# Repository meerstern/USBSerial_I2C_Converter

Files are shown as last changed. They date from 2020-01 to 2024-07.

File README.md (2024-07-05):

# USBシリアルI2C変換基板
USB Serial I2C Converter

## 概要 
  * USBシリアルをI2Cマスタに変換する基板です
  * シリアルCOMポートを介してPCやRPI等からI2Cデバイスを制御できます  
  * I2Cデバイスの動作確認やラピッドプロトタイピングに最適です  
  * シリアルCOM変換にPL2303GL、シリアルI2C変換に[SC18IM704][1]を使用しています(V2：現行モデル)  
  * シリアルCOM変換にPL2303SA、シリアルI2C変換にSC18IM700を使用しています(V1：旧モデル)  
  * TeratermやNode-Red、Unity、Python等からシリアルCOMポートを介して容易なコマンドでI2Cデバイスを制御できます  
  * I2CはGrove互換コネクタを搭載しています  
  * Grove互換コネクタの電源、プルアップ抵抗はスイッチ切り替えで5V/3.3Vに対応しています  
    ※USB、I2Cデバイスを接続する前に基板上のシルクを確認してから5V/3.3V切替してください  
    ※3.3V専用デバイスに5Vを加えないように注意してください  

## 詳細 
 * シリアルI2C変換SC18IM700/SC18IM704のコマンドは[データシート(PDF)][8]を参照してください  
 * シリアルI2C変換[SC18IM700/SC18IM704][1]のデフォルトボーレートは9600bpsです  
 * アドレスの異なる複数のデバイスを接続する場合は[I2Cハブ][7]を使用してください
 * 基板のピンヘッダを用いることでSC18IM700/SC18IM704単体の変換基板としても使用できます  
 * USB5V電源入力側に350mA定格のリセッタブルヒューズを搭載しています  
 * 給電可能な電流は3.3Vラインで最大150mA前後、5Vラインで最大350mAです
 * コマンドの応答がない場合はピンセット等でRSTピンとGNDピンを1秒程度短絡してリセットさせてください    

## USBドライバ
 * Windows版は[こちらからダウンロード][2]して使用してください  
 ※標準ドライバではNode-Redで動作不具合があるため、最新のドライバに更新し、再起動後に使用してください
 * Mac版は標準でドライバが読み込まれますが、必要に応じて[こちらからダウンロード][3]して使用してください  
 * Linux版はKernel 2.4.31以降、標準でドライバが組み込まれています  

## Node-Redサンプルフロー
 * シリアルポートフローを使用して[Grove温湿度センサSHT31][5]から温度、湿度を読み込む[サンプル][4]  
 * 温湿度センサ　SHT31、I2C接続LCD AQM1602、マルチ環境センサBME280、CO2センサ CCS811、リアルタイムクロック DS1307、AD変換 MCP3425、粒子センサ HM3301、赤外線グリッドセンサAMG8833、I2Cデバイス検索のサンプルコードがあります  
 ※詳細はサンプルコードをご確認ください  
 ※シリアルポートフローを使用する場合はオンプレミス版Node-Redを使用する必要があります。[こちらの記事][6]を参考にしてください  
 
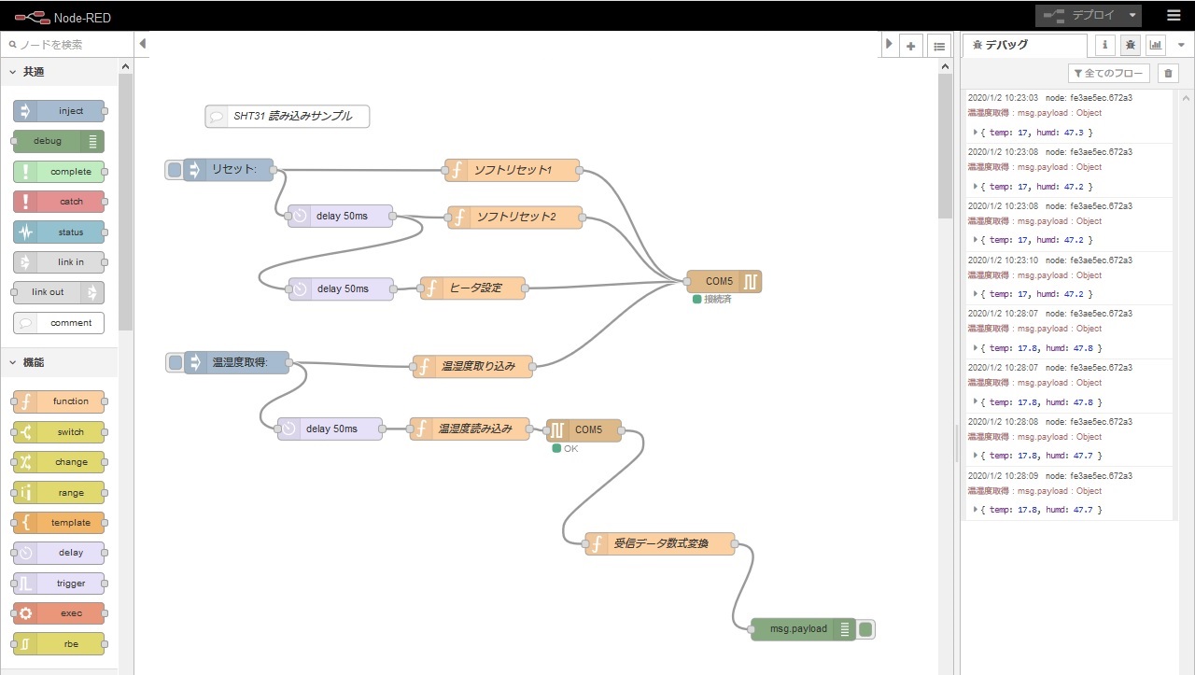
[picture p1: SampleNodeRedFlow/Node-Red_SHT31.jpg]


## Teratermサンプルマクロ
 * サンプルマクロを実行する際には必ず言語設定を「English」、「Default.lng」に設定してください。正しく送受信されません。  

## WebシリアルAPIツール
 * WebシリアルAPIを使用した[ツールを公開][9]しています  
 * EdgeもしくはChromeブラウザからアクセスすると簡単にI2Cデバイスと通信できます  
 * 対応デバイスは随時追加予定です  

## 変換基板
 * USBシリアルI2C変換基板の外観  

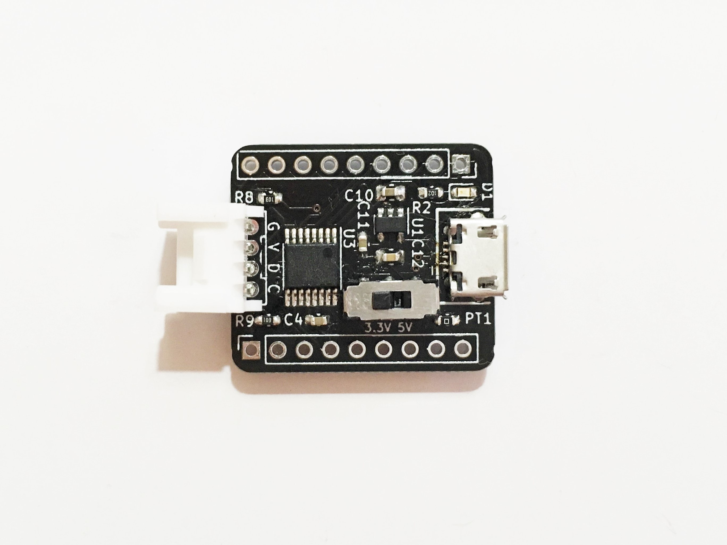
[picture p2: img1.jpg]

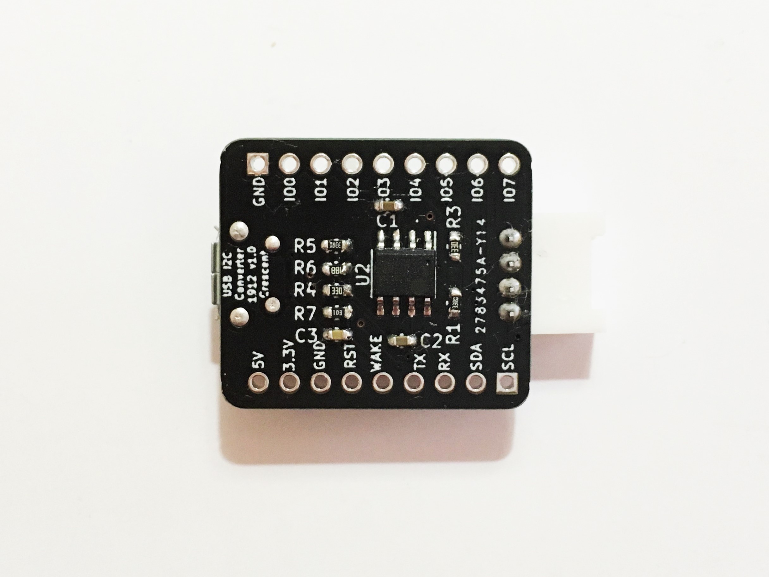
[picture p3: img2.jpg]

 
 ※上記写真は試作基板のため、量産版と異なる場合があります  
 
 ## 販売サイト
  * [スイッチサイエンス][10]
  
 ## 告知
  * SC18IM700、PL2303SAは生産完了のため、23年7月以降はそれぞれ後継機種のSC18IM704、PL2303GLを使用したv2.x基板に変更しました
  * SC18IM700/SC18IM704の基本的なI2Cコマンド等は互換性が維持されています
  * 生産完了に伴い、v1.xモデルの製造及び販売は終了しました  

# USB Serial I2C Converter
## Overview 

  * This is a board that converts USB serial to I2C master.
  * Can control I2C devices from PC, RPI, etc. via serial COM port
  * Ideal for I2C device operation verification and rapid prototyping
  * PL2303GL is used for serial COM conversion, and [SC18IM704][1] is used for serial I2C conversion (V2: current model)
  * Control I2C devices with easy commands via serial COM port from Teraterm, Node-Red, Unity, Python, etc.
  * I2C has Grove compatible connector  
  * Grove compatible connector power supply and pull-up resistor support 5V/3.3V by switching
  * Before connecting USB or I2C devices, please check the silk on the board and then switch 5V/3.3V.
  * Please be careful not to apply 5V to 3.3V only devices.

## Details 
  * For serial I2C conversion SC18IM700/SC18IM704 commands, please refer to [Datasheet (PDF)][8]
  * The default baud rate for serial I2C conversion [SC18IM700/SC18IM704][1] is 9600bps
  * When connecting multiple devices with different addresses, please use [I2C hub][7]
  * Can also be used as a conversion board for SC18IM700/SC18IM704 by using the pin header on the board
  * Equipped with a resettable fuse rated at 350mA on the USB5V power input side
  * The maximum current that can be supplied is around 150mA for 3.3V line, and 350mA for 5V line.
  * If there is no response to the command, short the RST pin and GND pin with tweezers for about 1 second to reset.

  ## USB Driver
  * For Windows version, please [download][2] from here.
  * The standard driver has a malfunction with Node-Red, so please update to the latest driver and use it after restarting.
  * The driver is loaded by default in the Mac version, but if necessary, please [download][3].
  * The Linux version has a built-in driver as standard since Kernel 2.4.31 

 ## Node-Red Sample Flow
  * Read temperature and humidity from [Grove temperature and humidity sensor SHT31][5] using serial port flow [sample][4]
  * Temperature and humidity sensor SHT31, I2C connection LCD AQM1602, multi-environment sensor BME280, CO2 sensor CCS811, real-time clock DS1307, AD conversion MCP3425, particle sensor HM3301, infrared grid sensor AMG8833, sample code for I2C device search is available
  * Please check the sample code for details.
  * If you want to use serial port flow, you need to use the on-premises version of Node-Red. Please refer to [this article(Japanese)][6]
 


## Teraterm Sample Macro
 * When running the sample macro, be sure to set the language settings to "English" and "Default.lng". It will not be sent or received correctly.

## Web Serial API Tools
 * [Publishing tools][11] using Web Serial API
 * Easily communicate with I2C devices when accessed from Edge or Chrome browsers
 * Compatible devices will be added

 ## Announcement
  * Production of SC18IM700 and PL2303SA has been discontinued, so from July 2023 onwards, we have changed to v2.x boards using the successor models SC18IM704 and PL2303GL, respectively.
  * Compatibility of basic I2C commands etc. of SC18IM700/SC18IM704 is maintained.
  * Due to the completion of production, the manufacture and sale of v1.x model has ended.

[1]: https://www.nxp.jp/part/SC18IM704PW#/
[2]: https://www.prolific.com.tw/UserFiles/files/PL23XX_Prolific_DriverInstaller_v408.zip
[3]: https://www.prolific.com.tw/UserFiles/files/PL2303HXD_G_Mac%20Driver_v2_1_0_20210311.zip
[4]: https://github.com/meerstern/USBSerial_I2C_Converter/tree/master/SampleNodeRedFlow
[5]: https://www.switch-science.com/catalog/2853/
[6]: http://meerstern.seesaa.net/article/465007276.html
[7]: https://www.switch-science.com/catalog/796/
[8]: https://www.nxp.jp/docs/en/data-sheet/SC18IM704.pdf
[9]: https://meerstern.github.io/
[10]: https://www.switch-science.com/products/6214
[11]: https://meerstern.github.io/Web%20API%20Tools_En.html

MIT Lisense

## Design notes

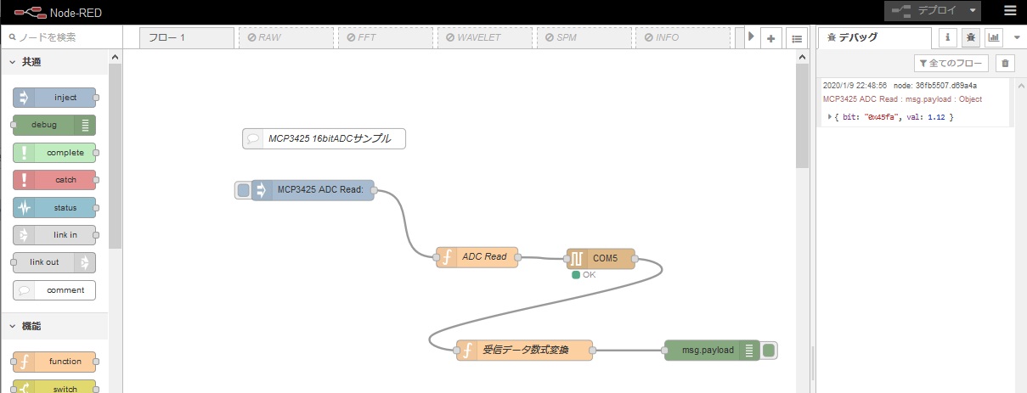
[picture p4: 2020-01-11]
SampleNodeRedFlow/Node-Red_MCP3425.jpg

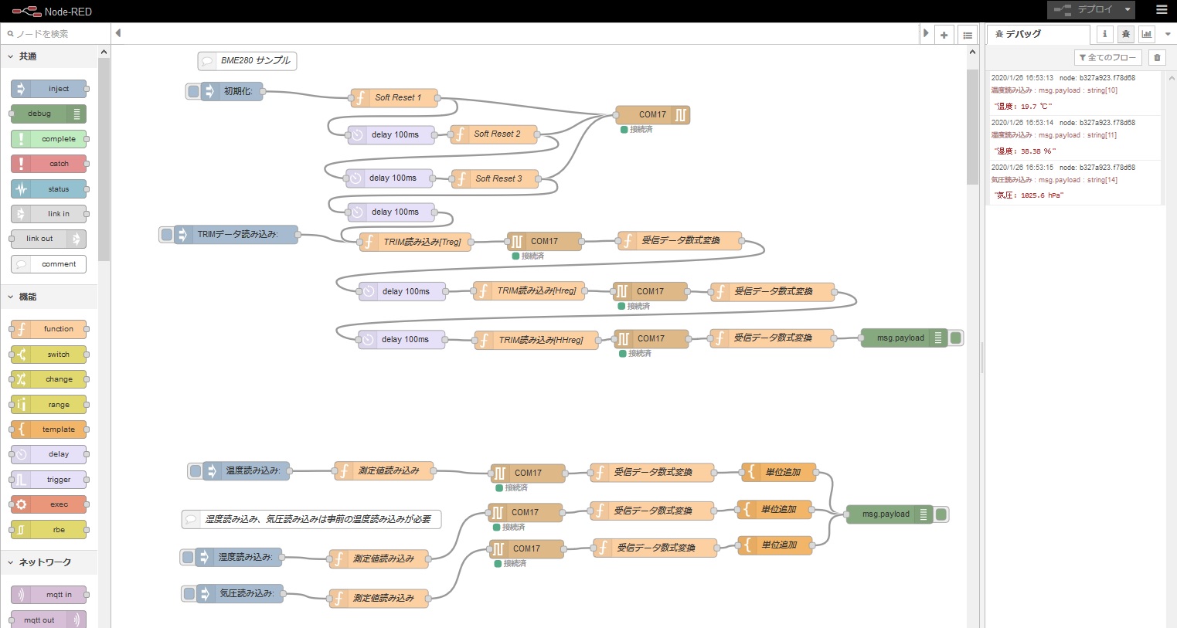
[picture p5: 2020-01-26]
SampleNodeRedFlow/Node-Red_BME280.jpg

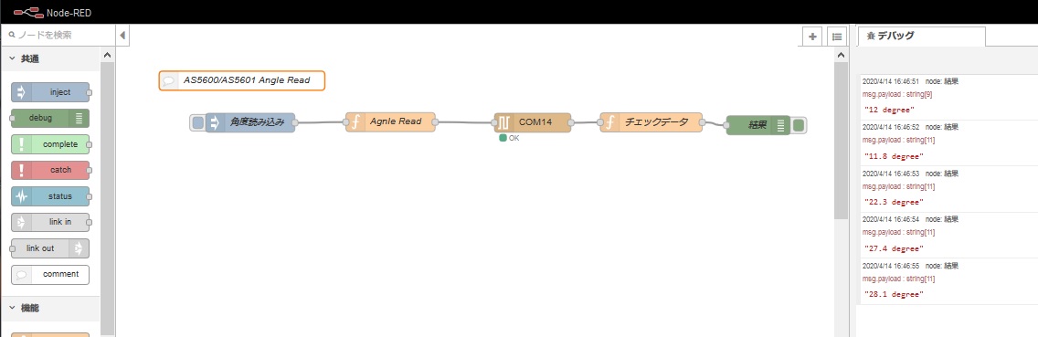
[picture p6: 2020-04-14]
SampleNodeRedFlow/Node-Red_AS5600,AS5601.jpg

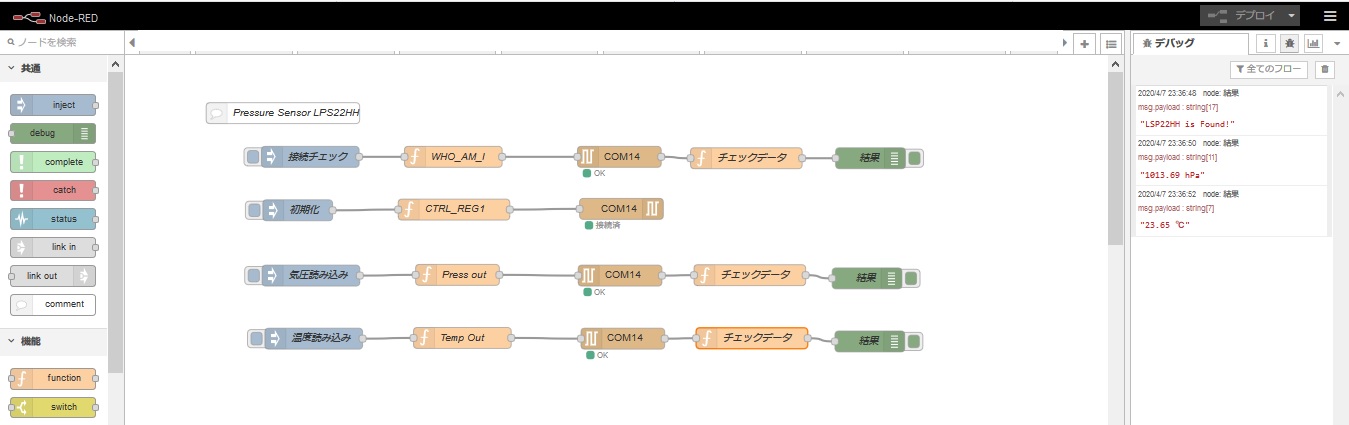
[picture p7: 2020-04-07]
SampleNodeRedFlow/Node-Red_LPS22HH.jpg

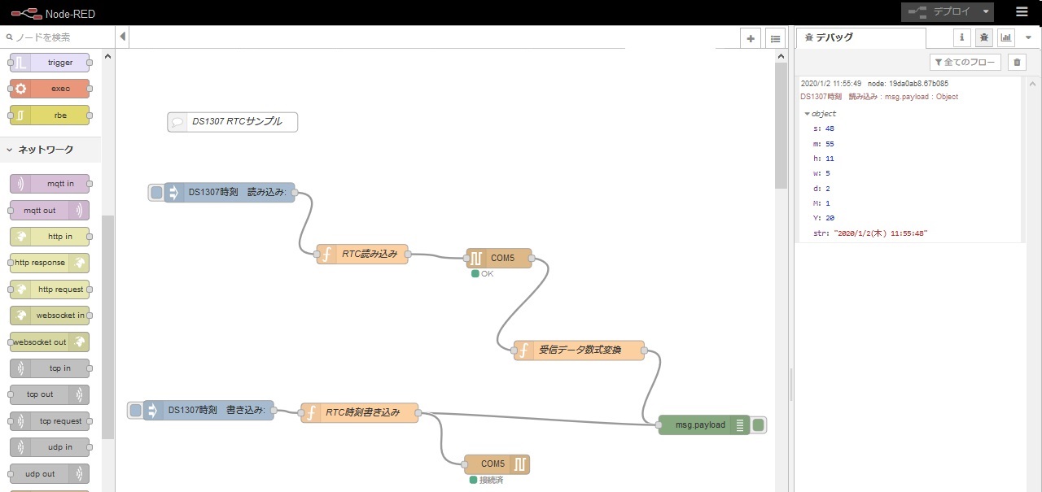
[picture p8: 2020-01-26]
SampleNodeRedFlow/Node-Red_DS1307.jpg

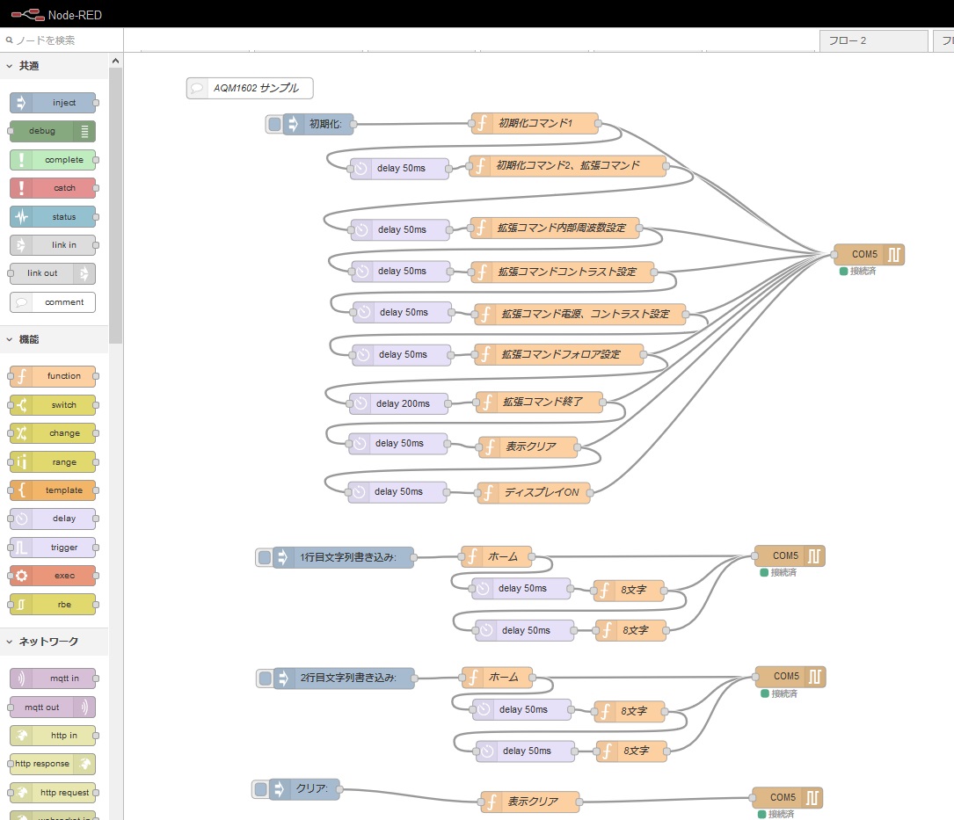
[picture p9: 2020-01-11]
SampleNodeRedFlow/Node-Red_AQM1602.jpg

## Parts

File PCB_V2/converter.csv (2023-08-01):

ID | 参照記号 | パッケージ | 数 | 名称 | Supplier and ref
1 | R10,R7 | R_0603_1608Metric | 2 | 10k
2 | U3 | TSSOP-16_4.4x5mm_P0.65mm | 1 | SC18IM704
3 | C1,C2,C4 | C_0603_1608Metric | 3 | 0.1u
4 | C10,C12 | C_0805_2012Metric | 2 | 10u
5 | C11 | C_0603_1608Metric | 1 | 0.01u
6 | D1 | LED_0603_1608Metric | 1 | LED
7 | M1 | CONN-10118194-0001LF-FCI | 1 | MICRO-USB-ZX62R-B-5P-con-hirose
8 | PT1 | R_0603_1608Metric | 1 | femtoSMDC035F-02
9 | R1,R3,R4,R5 | R_0603_1608Metric | 4 | 27
10 | R2 | R_0603_1608Metric | 1 | 1k
11 | R6 | R_0603_1608Metric | 1 | 1.5k
12 | U1 | SOT-23-5 | 1 | LD3985M33R
13 | U2 | SOIC-8_3.9x4.9mm_P1.27mm | 1 | PL2303SA
14 | J1 | GROVE | 1 | Conn_01x04
15 | J2,J3 | PinSocket_1x09_P2.54mm_Vertical | 2 | Conn_01x09
16 | R8,R9 | R_0603_1608Metric | 2 | 4.7k
17 | SW1 | DPDT_SMD | 1 | SW_SPDT

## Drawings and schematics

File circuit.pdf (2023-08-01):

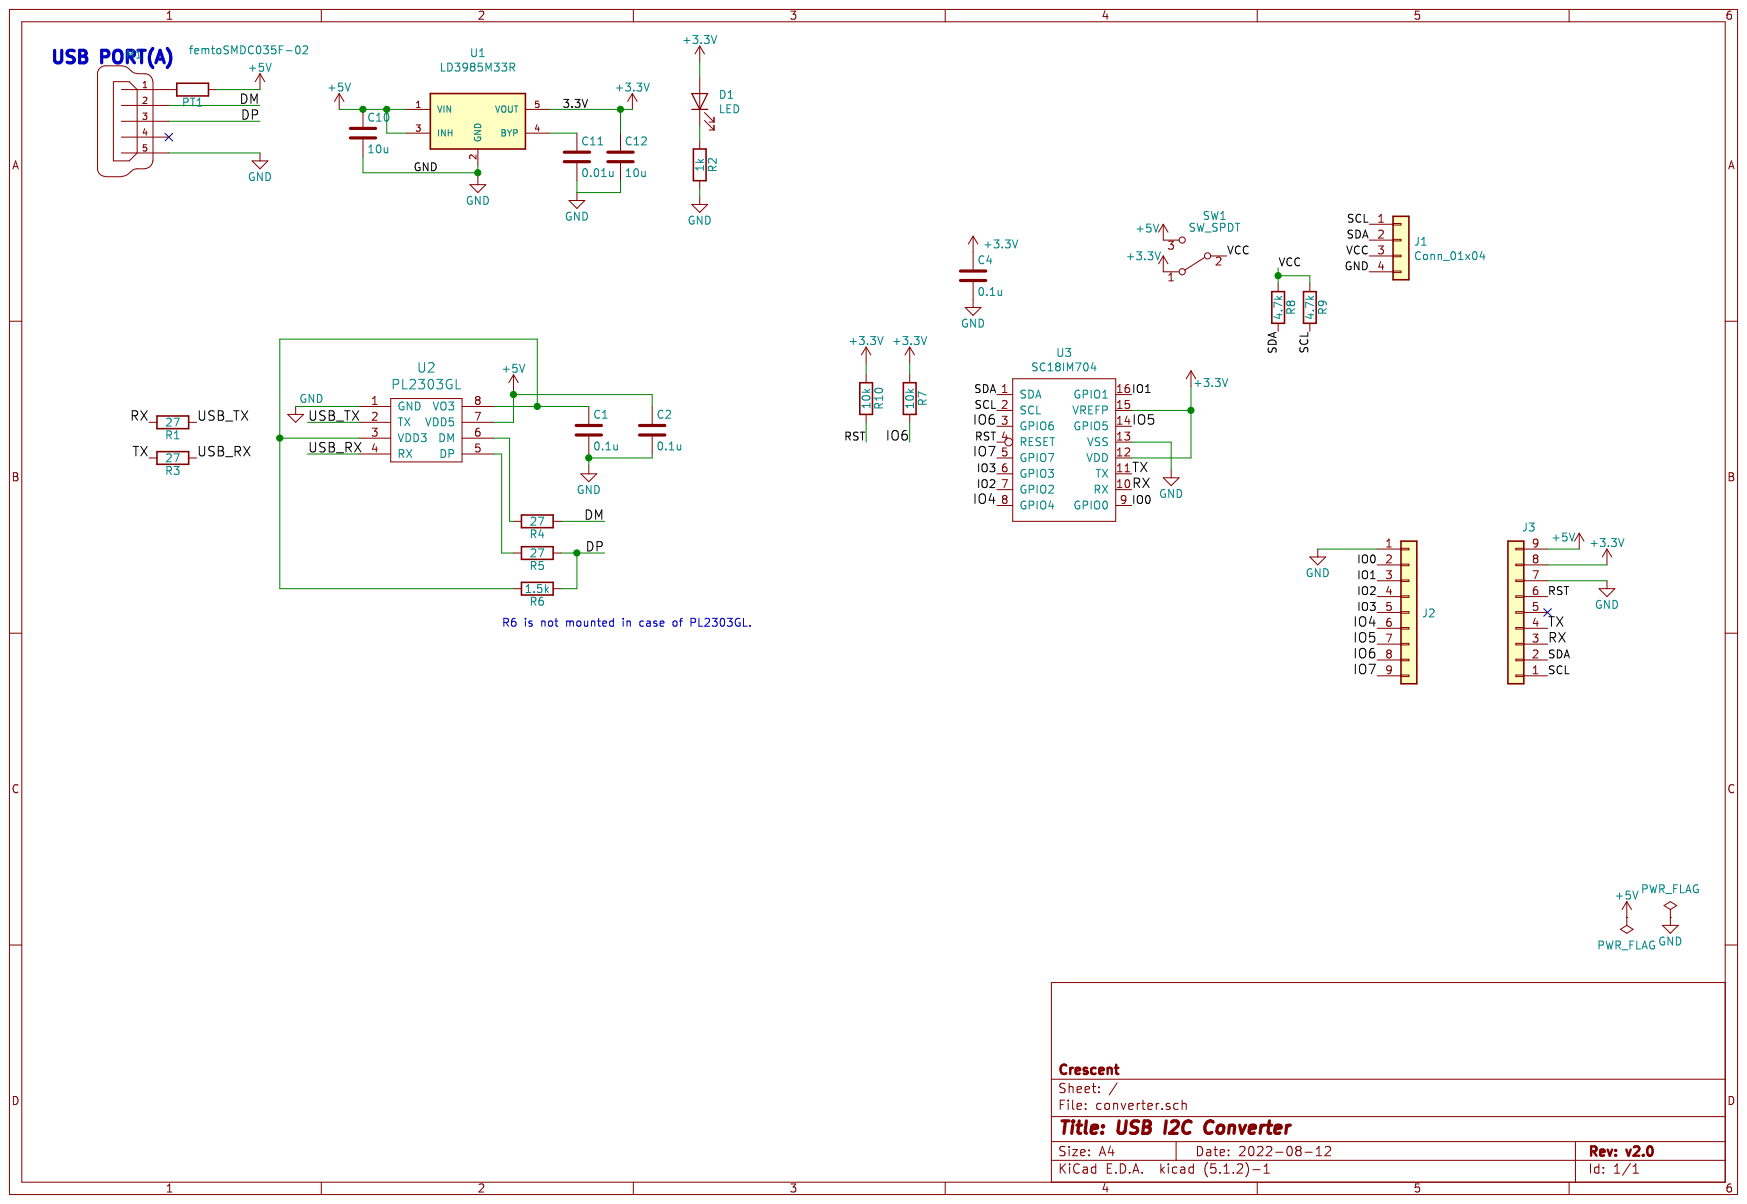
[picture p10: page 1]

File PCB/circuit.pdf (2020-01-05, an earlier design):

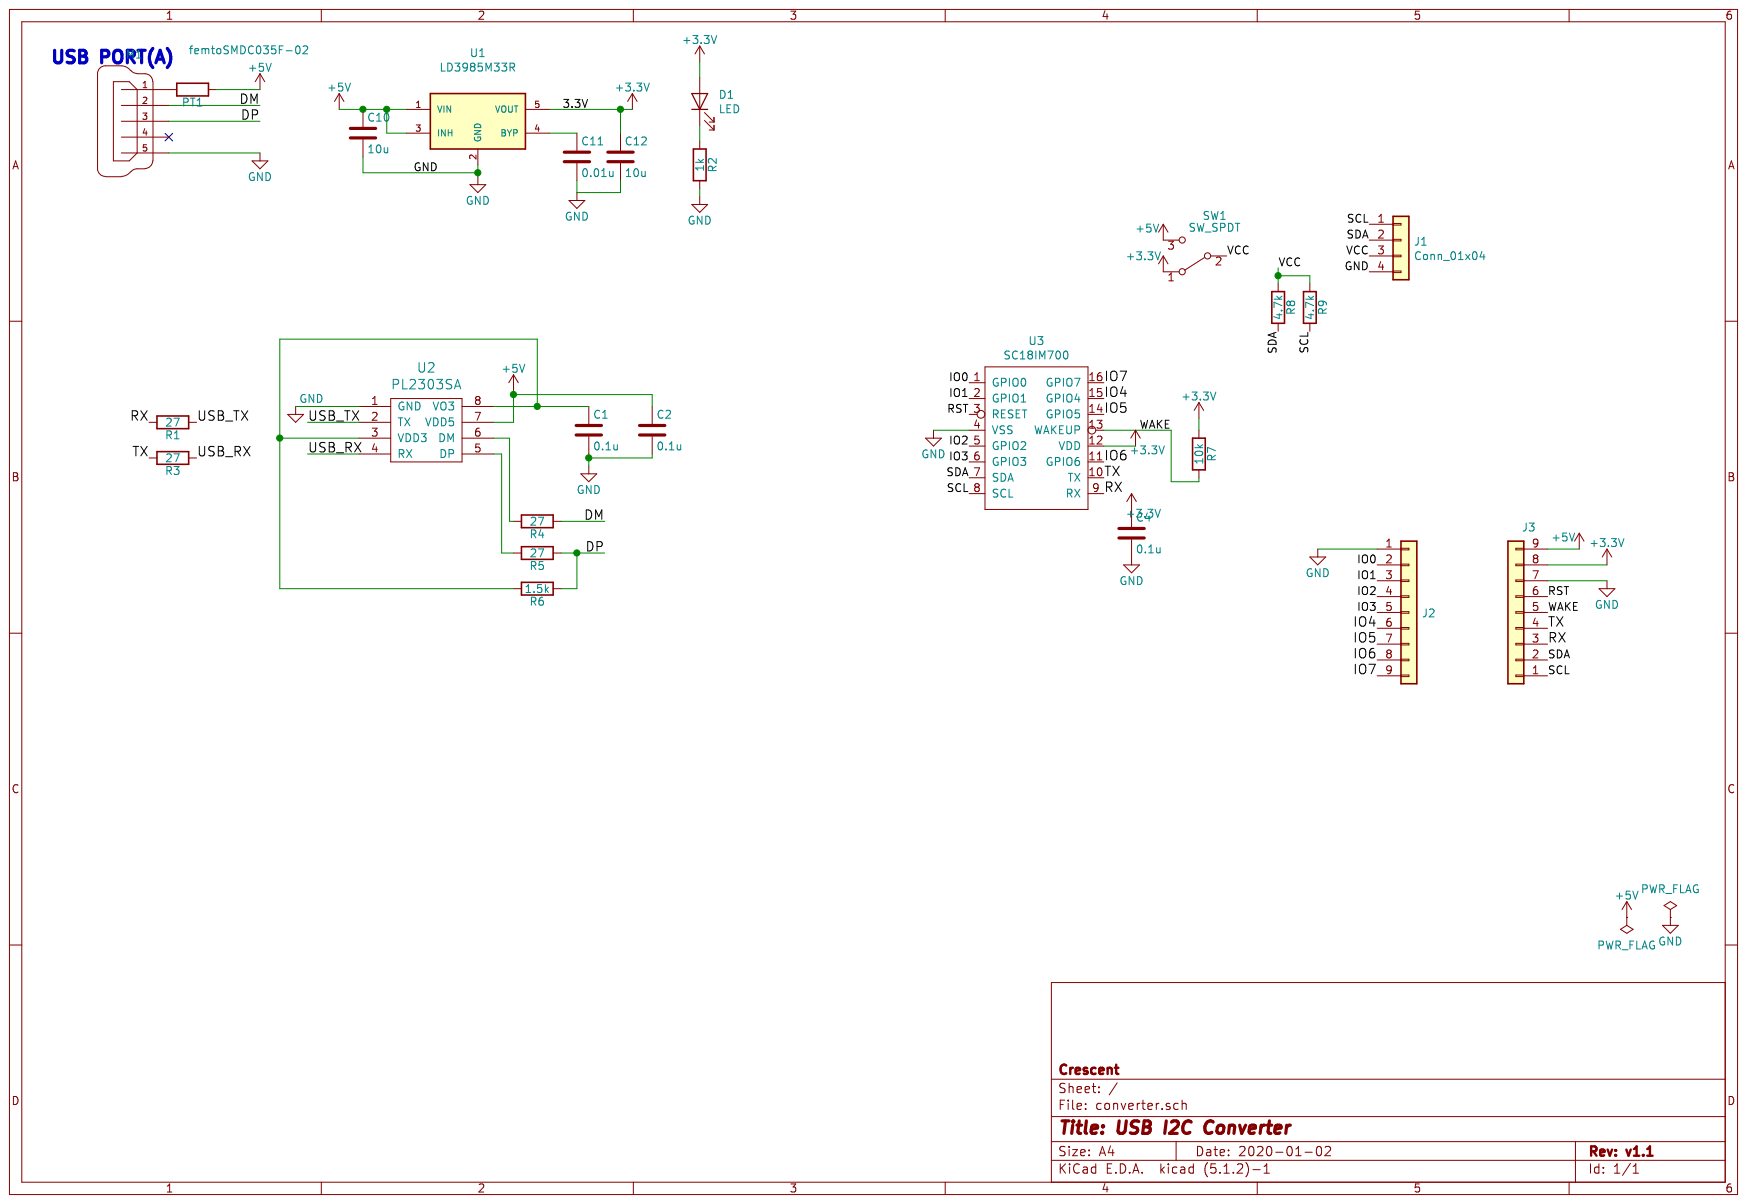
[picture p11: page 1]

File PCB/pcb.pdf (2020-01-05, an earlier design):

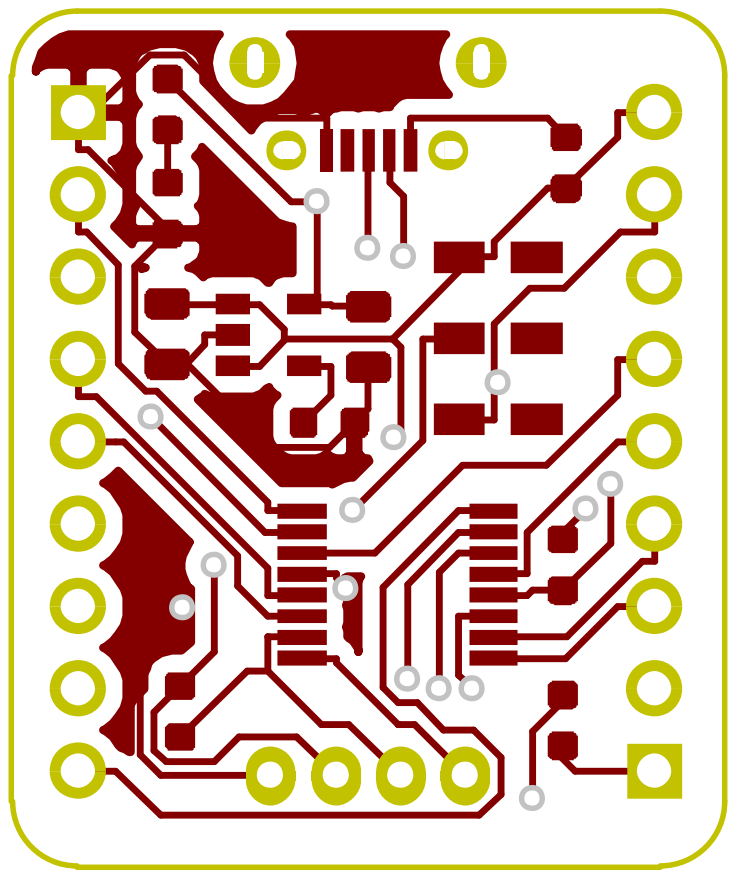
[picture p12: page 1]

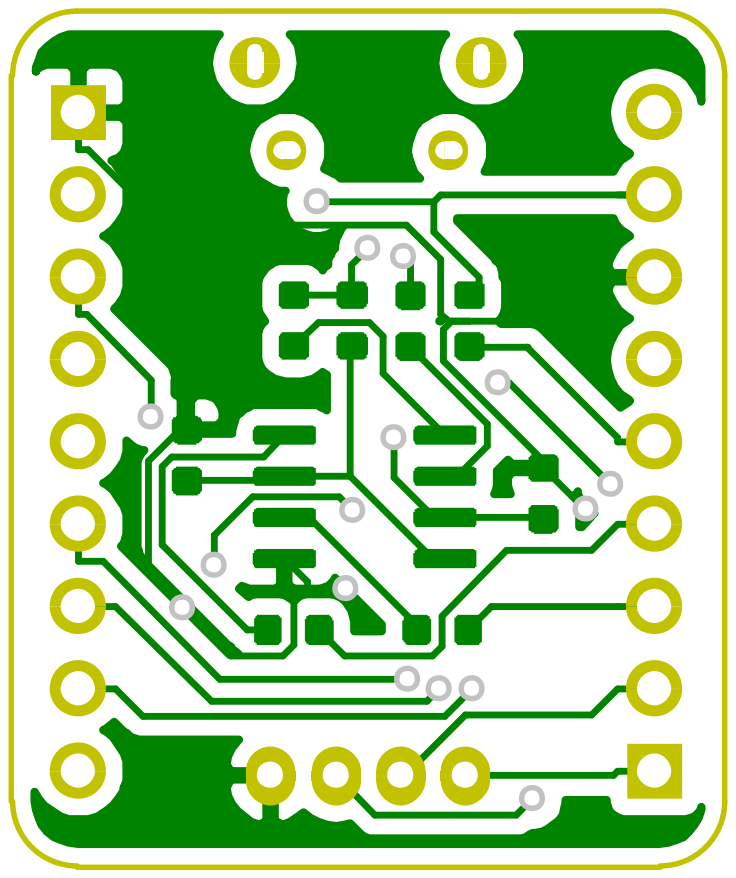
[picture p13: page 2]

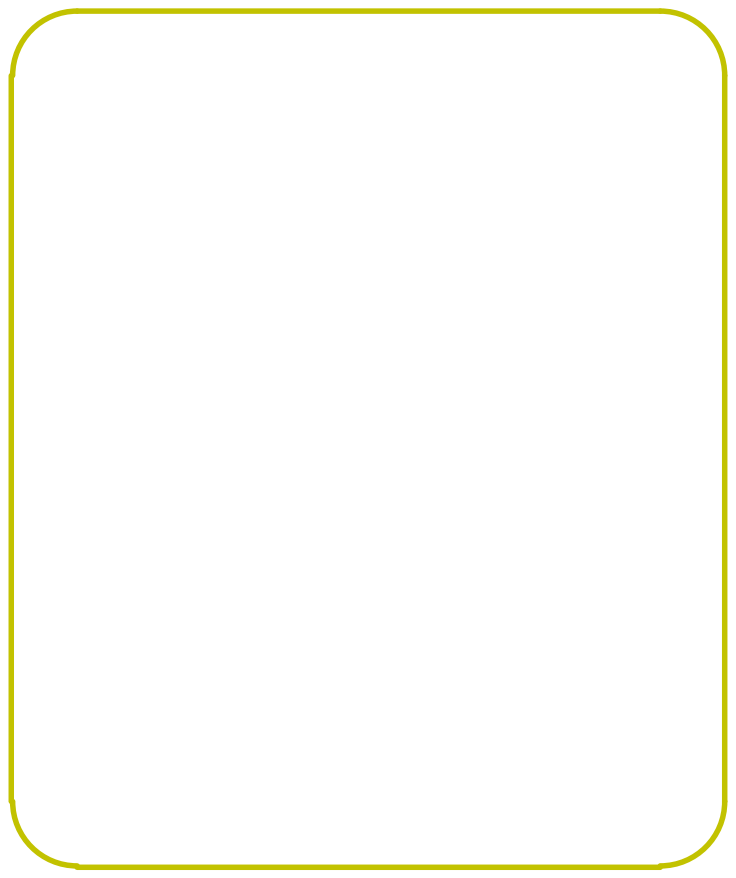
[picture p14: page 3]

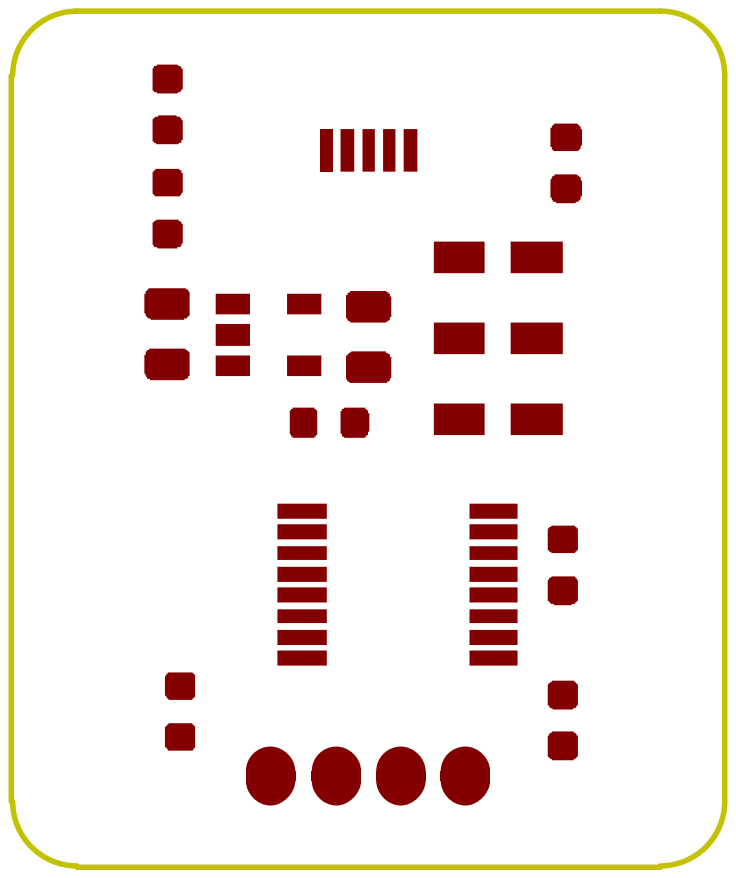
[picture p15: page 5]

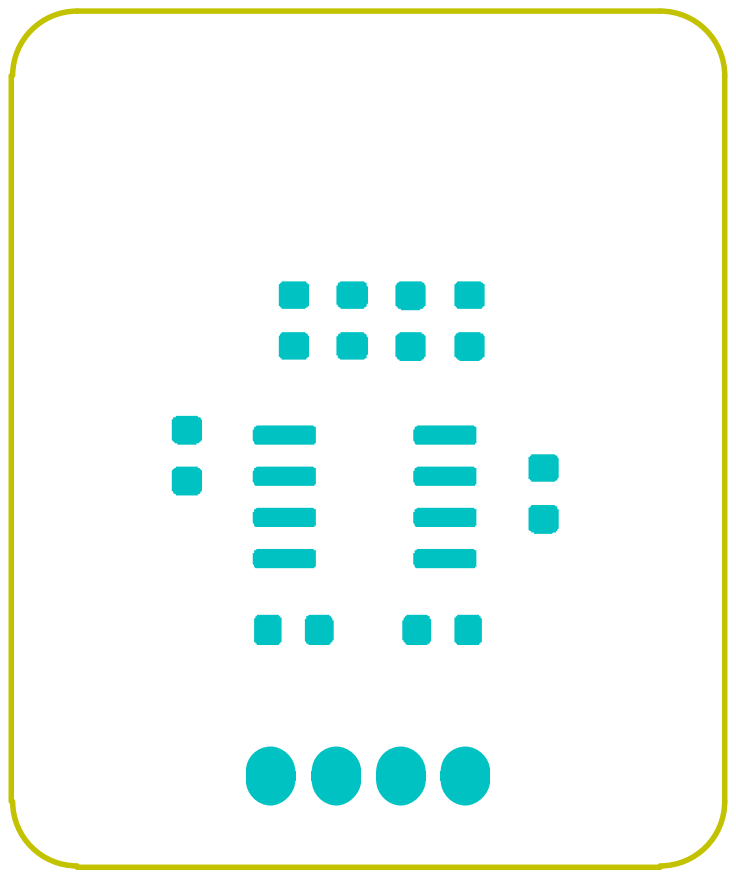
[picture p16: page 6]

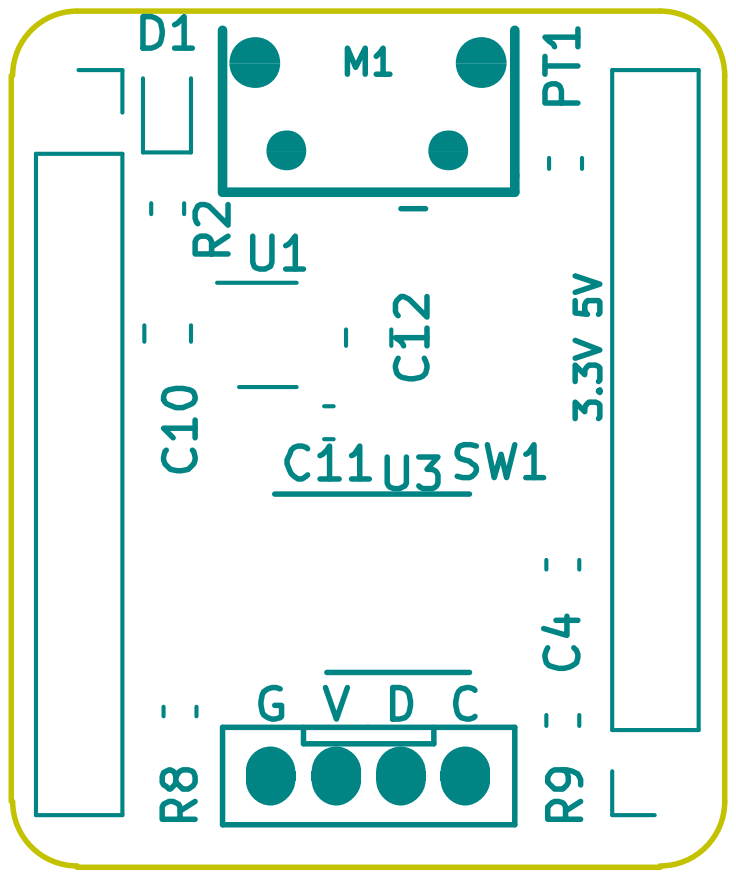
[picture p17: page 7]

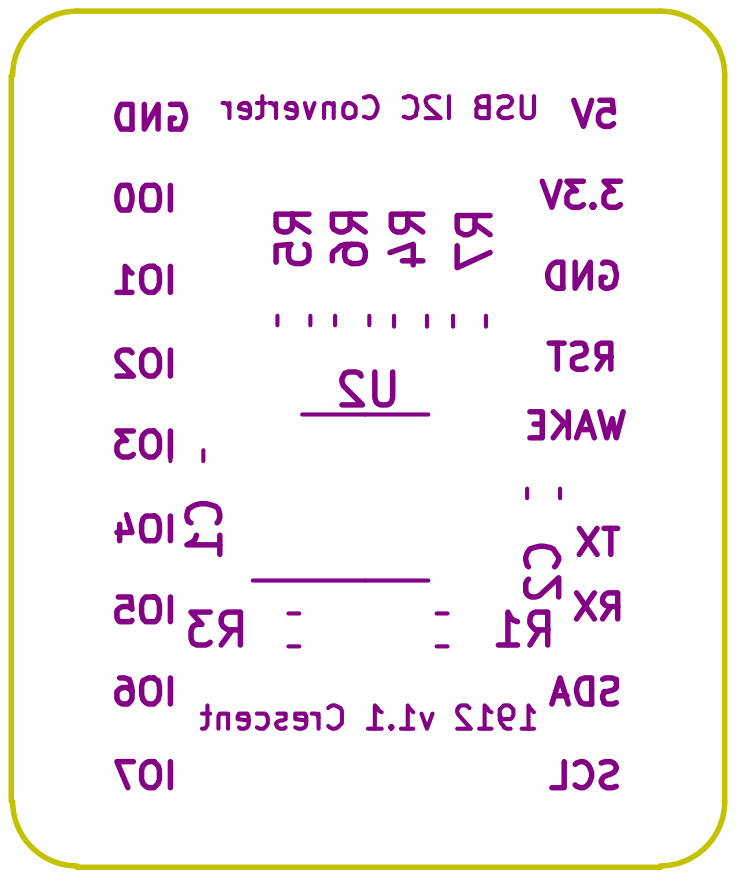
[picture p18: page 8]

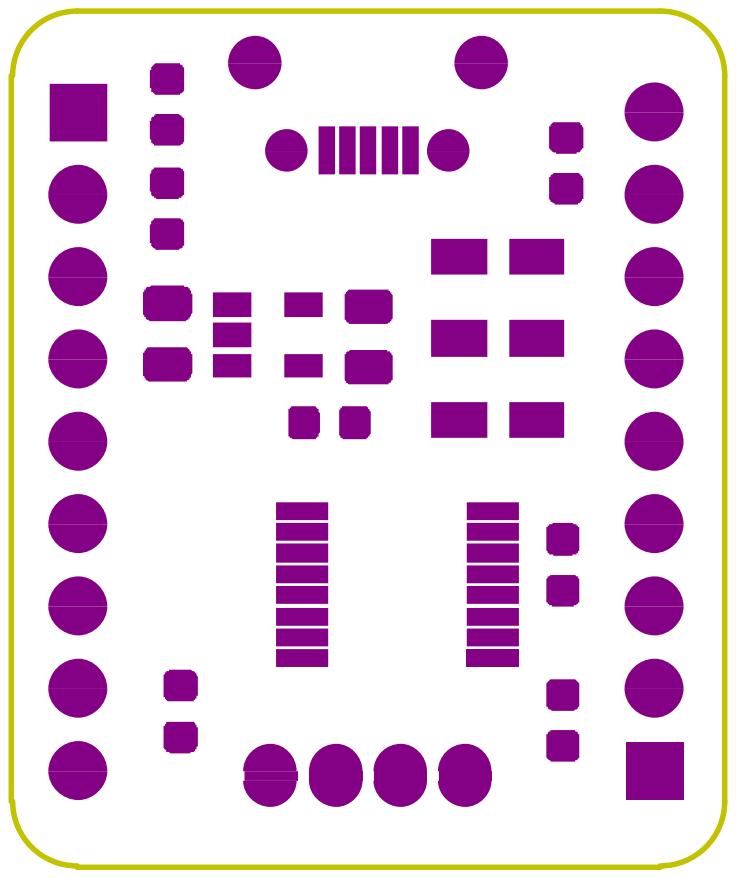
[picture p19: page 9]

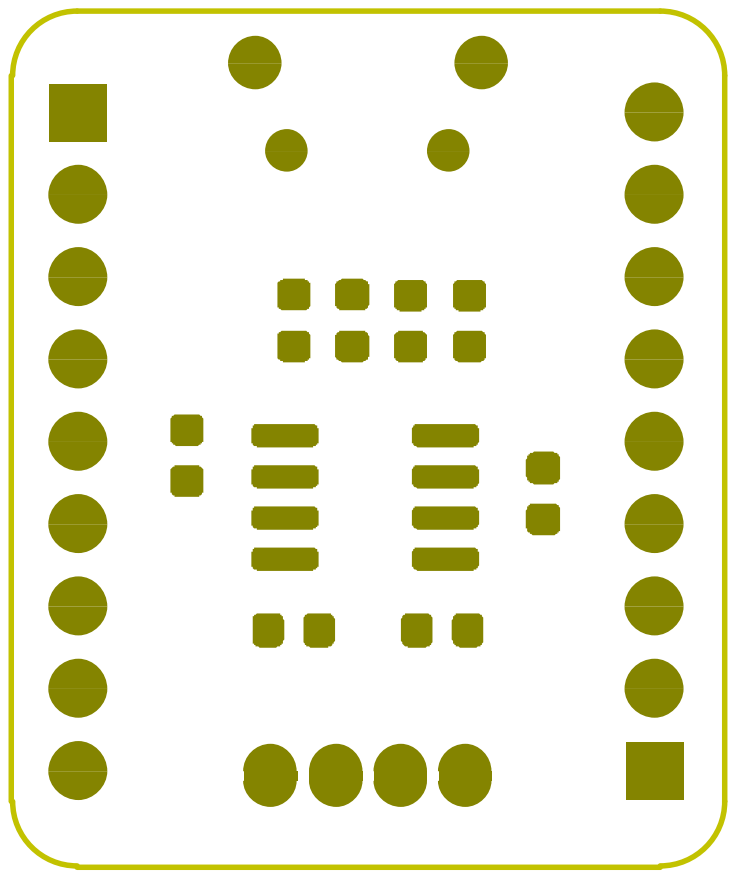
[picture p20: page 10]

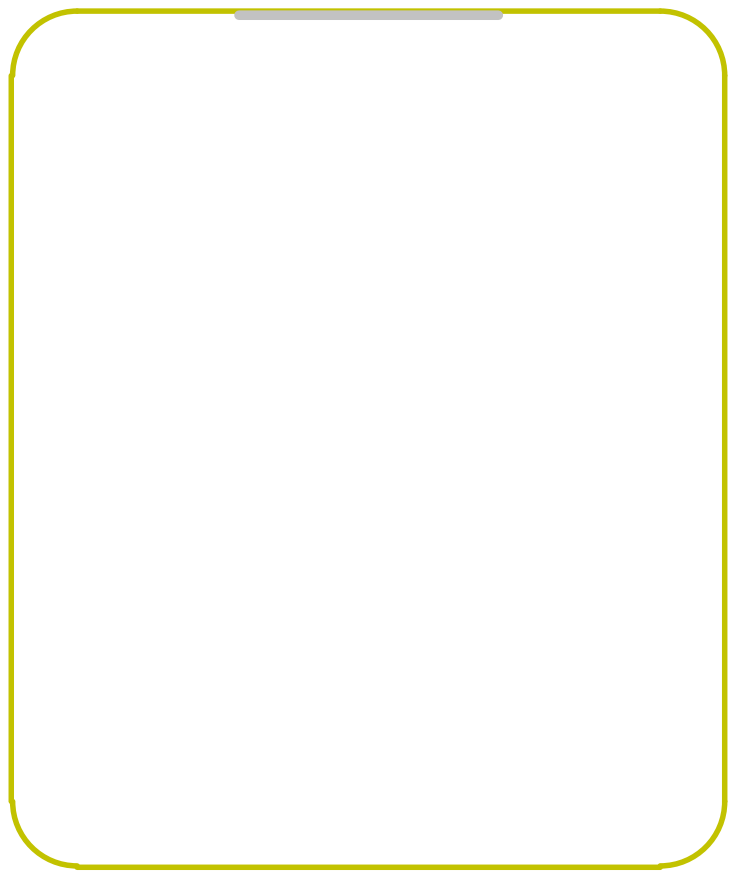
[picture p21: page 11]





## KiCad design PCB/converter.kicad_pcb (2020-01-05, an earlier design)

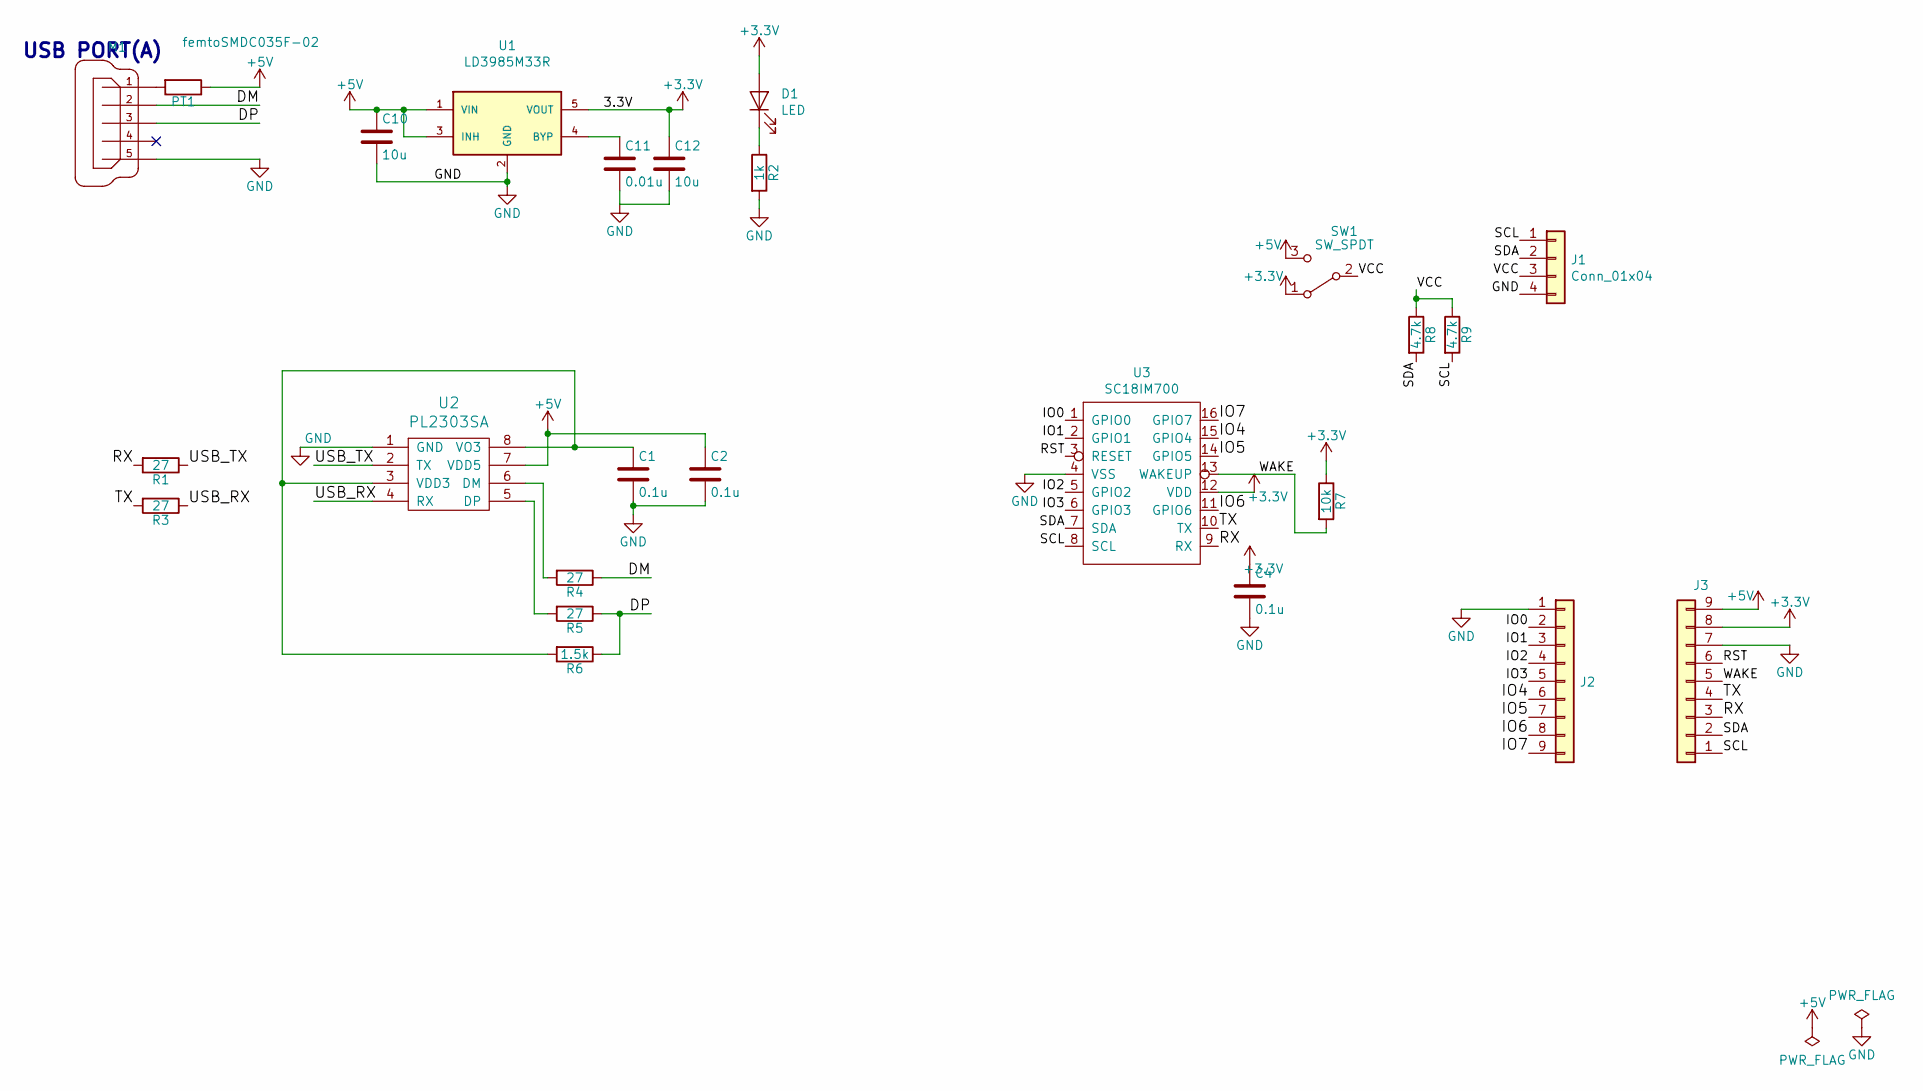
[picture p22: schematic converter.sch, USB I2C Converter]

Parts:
C1, C2, C4: 0.1u; C_0603_1608Metric
C10, C12: 10u; C_0805_2012Metric
C11: 0.01u; C_0603_1608Metric
D1: LED; LED_0603_1608Metric
J1: Conn_01x04; GROVE
J2, J3: Conn_01x09; PinSocket_1x09_P2.54mm_Vertical
M1: MICRO-USB-ZX62R-B-5P-con-hirose; CONN-10118194-0001LF-FCI
PT1: femtoSMDC035F-02; R_0603_1608Metric
R1, R3, R4, R5: 27; R_0603_1608Metric
R2: 1k; R_0603_1608Metric
R6: 1.5k; R_0603_1608Metric
R7: 10k; R_0603_1608Metric
R8, R9: 4.7k; R_0603_1608Metric
SW1: SW_SPDT; DPDT_SMD
U1: LD3985M33R; SOT-23-5
U2: PL2303SA; SOIC-8_3.9x4.9mm_P1.27mm
U3: SC18IM700; TSSOP-16_4.4x5mm_P0.65mm

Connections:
+3V3: C4.1, C12.1, D1.2 (A), J3.8, R7.1, SW1.1 (A), U1.5 (VOUT), U3.12 (VDD)
+5V: C2.1, C10.1, J3.9, PT1.1, SW1.3 (C), U1.1 (VIN), U1.3 (INH), U2.7 (VDD5)
/DM: M1.2, R4.1
/DP: M1.3, R5.1, R6.1
/IO0: J2.2, U3.1 (GPIO0)
/IO1: J2.3, U3.2 (GPIO1)
/IO2: J2.4, U3.5 (GPIO2)
/IO3: J2.5, U3.6 (GPIO3)
/IO4: J2.6, U3.15 (GPIO4)
/IO5: J2.7, U3.14 (GPIO5)
/IO6: J2.8, U3.11 (GPIO6)
/IO7: J2.9, U3.16 (GPIO7)
/RST: J3.6, U3.3 (RESET)
/RX: J3.3, R1.2, U3.9 (RX)
/SCL: J1.1, J3.1, R9.2, U3.8 (SCL)
/SDA: J1.2, J3.2, R8.2, U3.7 (SDA)
/TX: J3.4, R3.2, U3.10 (TX)
/USB_RX: R3.1, U2.4 (RX)
/USB_TX: R1.1, U2.2 (TX)
/VCC: J1.3, R8.1, R9.1, SW1.2 (B)
/WAKE: J3.5, R7.2, U3.13 (WAKEUP)
GND: C1.2, C2.2, C4.2, C10.2, C11.2, C12.2, J1.4, J2.1, J3.7, M1.5, R2.2, U1.2 (GND), U2.1 (GND), U3.4 (VSS)
unnamed: C1.1, R6.2, U2.3 (VDD3), U2.8 (VO3)
unnamed: C11.1, U1.4 (BYP)
unnamed: D1.1 (K), R2.1
unnamed: M1.1, PT1.2
unnamed: R4.2, U2.6 (DM)
unnamed: R5.2, U2.5 (DP)

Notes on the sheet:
USB PORT(A)

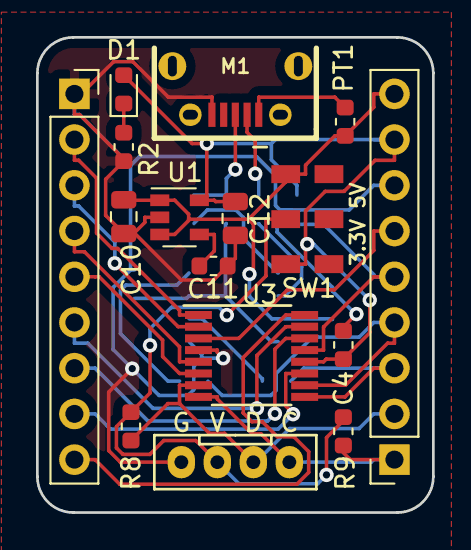
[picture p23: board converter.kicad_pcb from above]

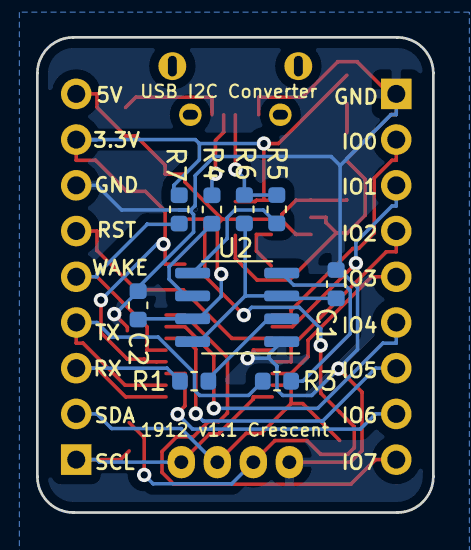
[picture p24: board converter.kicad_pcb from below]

Board: 2 copper layers, 22.0 x 26.4 mm, 25 parts (9 on the bottom side), 28 nets.

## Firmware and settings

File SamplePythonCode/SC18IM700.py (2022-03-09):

#!/usr/bin/env python
'''
    Driver for USB I2C Converter with SC18IM700
    Crescent　2203　v1.0

'''
import serial
import time

I2C_BUS_START_CMD=b'S'
I2C_BUS_STOP_CMD=b'P'
REG_READ_CMD=b'R'
REG_WRITE_CMD=b'W'
GPIO_READ_CMD=b'I'
GPIO_WRITE_CMD=b'O'

class USBI2CCONV:

    def __init__(self, port):
        self.ser = serial.Serial(port, baudrate=9600,bytesize=8, parity='N', stopbits=1, timeout=0.5)
        if(self.ser.isOpen() == False):
            self.ser.open()
        print("Serial Port Connected")
        
    def __del__(self):
        if(self.ser.isOpen() == True):
            self.ser.close();
        print("Serial Port Closed")   
        
    def _i2c_write_addr(self, addr): 
        return (addr << 1) & 0xFE
    
    def _i2c_read_addr(self, addr): 
        return (addr << 1) | 0x01
       
    
    def _tx(self, data):
        self.ser.write(data)
        time.sleep(10/1000)
        #print("Wrote 0x{:X}".format(data))  
        
    def _rx(self, size=1):
        res = self.ser.read(size)
        #res = self.ser.read_all()
        #print("Read 0x{:X}".format(res))
        return res
    
    def reg_write(self, reg, data):
        wdata = REG_WRITE_CMD + bytes([reg]) + bytes([data]) + I2C_BUS_STOP_CMD
        self._tx(wdata)

    def reg_read(self, reg):
        wdata = REG_READ_CMD + bytes([reg]) + I2C_BUS_STOP_CMD
        self._tx(wdata)
        return self._rx(1)
    
    def timeout_enable(self):
        self.reg_write(0x09, 0x67)
    
    def i2c_write(self, i2c_addr, data):
        size = len(data)
        addr = self._i2c_write_addr(i2c_addr)
        wdata = I2C_BUS_START_CMD + bytes([addr, size]) + bytes(data) + I2C_BUS_STOP_CMD
        self._tx(wdata)
   
    def i2c_read(self, i2c_addr, num=1):
        addr = self._i2c_read_addr(i2c_addr)
        wdata = I2C_BUS_START_CMD + bytes([addr, num]) + I2C_BUS_STOP_CMD
        self._tx(wdata)
        return self._rx(num)
    
    def i2c_write_read(self, i2c_addr, write_data, read_num=1):
        wadd = self._i2c_write_addr(i2c_addr)
        raddr= self._i2c_read_addr(i2c_addr)
        size = len(write_data)
        wdata = I2C_BUS_START_CMD + bytes([wadd]) + bytes([size]) + bytes(write_data) 
        self._tx(wdata)
        time.sleep(10/1000)
        wdata = I2C_BUS_START_CMD + bytes([raddr, read_num]) + I2C_BUS_STOP_CMD
        self._tx(wdata)
        time.sleep(10/1000)
        return self._rx(read_num)
    
	    
    def io_read(self):
        return self.reg_read(0x04)
    
    def io_write(self, data):
        return self.reg_write(0x04, data)
    
    def io_conf_set(self, conf):
        self.reg_write(0x02, conf[0])
        self.reg_write(0x03, conf[1])
	
    def i2c_device_search(self):
		self.timeout_enable()
        devlist=[]
        print('*I2C Device Search Start*')
        for addr in range(0x00, 0x7F, 0x02):
            res=self.i2c_read(addr,1)
            if res!=b'':
                print('Device Found: 0x' + '{:X}'.format(addr) + ' (7bit Address)')
                devlist.append(addr)
                #time.sleep(10/1000)
        print('*I2C Device Search End*')
        return devlist
    

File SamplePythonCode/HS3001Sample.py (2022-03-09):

from SC18IM700 import USBI2CCONV 
conv = USBI2CCONV(port='COM14')
#HS3001

# Pattern1 write_read
i2caddr=0x44
wdata = [0x00]
conv.i2c_write(i2caddr,wdata)
time.sleep(30/1000)
res=conv.i2c_write_read(0x44,wdata,4)

#Calc Humd
hmd=((res[0]&0x3F)<<8)+res[1]
hmdf=hmd/(pow(2,14)-1)*100.0
#Calc Temp
tmp=(res[2]<<8)+res[3]
tmp=tmp>>2
tmpf=tmp/(pow(2,14)-1)*165-40
print('TEMP: ' + '{:.2f}'.format(tmpf) + ' ℃')
print('HUMD: ' + '{:.2f}'.format(hmdf)+' ％')

# Pattern2 write & read
i2caddr=0x44 #7bit Addr (without R/W bit)
rdata = 4
wdata = [0x00]
conv.i2c_write(i2caddr,wdata)
time.sleep(30/1000)
res=conv.i2c_read(i2caddr,rdata)
#Calc Humd
hmd=((res[0]&0x3F)<<8)+res[1]
hmdf=hmd/(pow(2,14)-1)*100.0
#Calc Temp
tmp=(res[2]<<8)+res[3]
tmp=tmp>>2
tmpf=tmp/(pow(2,14)-1)*165-40
print('TEMP: ' + '{:.2f}'.format(tmpf) + ' ℃')
print('HUMD: ' + '{:.2f}'.format(hmdf)+' ％')
del conv

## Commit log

2020-01-05 Init upload
    [Calc.xlsx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]
2020-01-11 Add Sample Code
    MCP3425、AQM1602、I2C Device search
2020-01-14 Add sample flow of CCS811 CO2 sensor
2020-01-21 Add Node-Red Code for particle sensor, HM3301
2020-01-26 Add BME280 flows
2020-01-31 Add sample code for AMG8833
2020-02-11 Add EEPROM sample and VL53L0 sample
2020-02-22 Add VL53L1 & GPIO samples
2020-03-08 Add MLX90614 sample flow
2020-04-07 Add Pressure sensor of LPS22HH from ST
2020-04-14 Add AMS Angle Sensor AS5600, AS5601
2020-06-14 Add CO2 sensor with SGP30
2020-08-22 Add flows for ADC121C021
2021-08-17 Add flow of RTC RV-8803-C7
2022-03-01 Add I2C Timeout Setting
2022-03-09 Add Python Sample Code for Python3
2022-08-22 Updated Driver Link
2023-08-01 Add pcb files for V2
    [converter-B_Cu.gbl, converter-B_Mask.gbs, converter-B_Paste.gbp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]
